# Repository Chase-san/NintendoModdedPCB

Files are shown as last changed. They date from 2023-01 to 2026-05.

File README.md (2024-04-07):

# NintendoModdedPCB

Modifications of my remakes various Nintendo PCB with KiCAD. Usually for F-RAM and battery.

These were designed with the help of Mhouranix1125, which created the excellent [DMG-KGDU-10+](https://github.com/Mhouranix1125/DMG-KGDU-10-Plus-FRAM-Upgraded-PCB)

# License

These boards are released under the Creative Commons Attribution 4.0 International License. See the LICENSE for more details. These boards are intended specifically for the modification of official games. There are better boards for creating flash carts.

# Boards

Click the revision to go to that release of the board (gerber files).

| ID | MOD | Revision |
| :--- | :--- | :---: |
| DMG-A02-MOD | F-RAM | [REV2](https://github.com/Chase-san/NintendoModdedPCB/releases/tag/dmg-a02-mod-rev2) |
| DMG-KGDU-MOD2 | F-RAM, BATTERY | [REV2](https://github.com/Chase-san/NintendoModdedPCB/releases/tag/dmg-kgdu-mod2-rev2) |

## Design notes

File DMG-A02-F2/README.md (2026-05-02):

# DMG-A02-MOD

This is an F-RAM and battery holder upgrade to the DMG-A02-10. This board is good for Pokemon Red, Blue, and Yellow as well many other games.

## Components

This board features a 32-pin ROM and a 28-pin RAM module.

| Ref | Package | Description  | Notes | Part |
| :---: | :---: | :--- | :---- | :--- |
| U1 | SSOP-32W | Program ROM  | | |
| U2 | LQFP-32 | MBC-5 | | |
| U3 | SOIC-28W | F-RAM | | |
| U4 | TSOP-6 | Clock Sync | OR Gate | 74LVC1G332GV,125 |
| C1, C2, C3, C4, C5 | 0603 (in) |  0.015uF - 0.1uF Capacitor | |
| C6 | 0603 (in) | 33pF Capacitor | May be left empty | |
| R1 | 0603 (in) | 10k Ohm Resistor | | |

## Change Log

### REV2 (2023-01-29)
- Added teardrops.

### REV1 (2023-01-21)
- Initial creation.

## Images
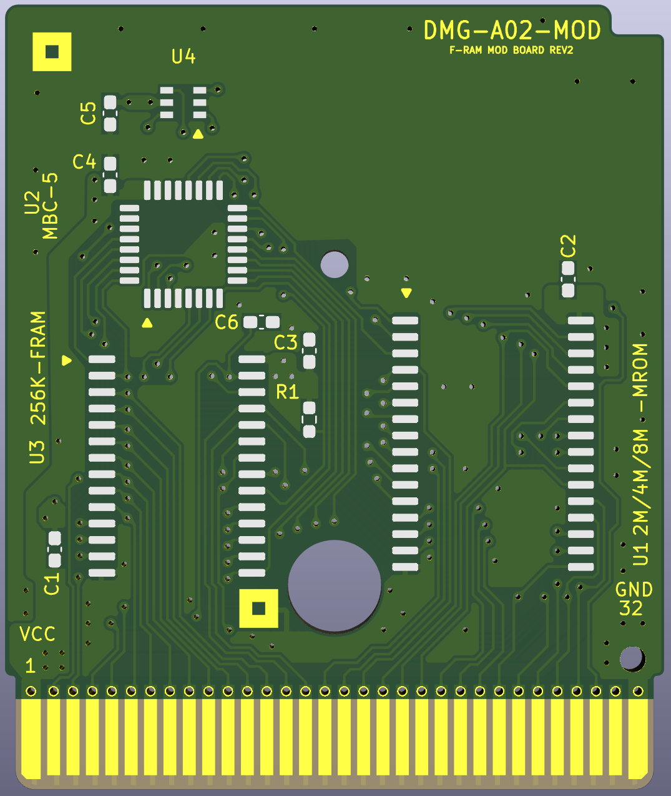
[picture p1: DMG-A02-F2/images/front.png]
Front

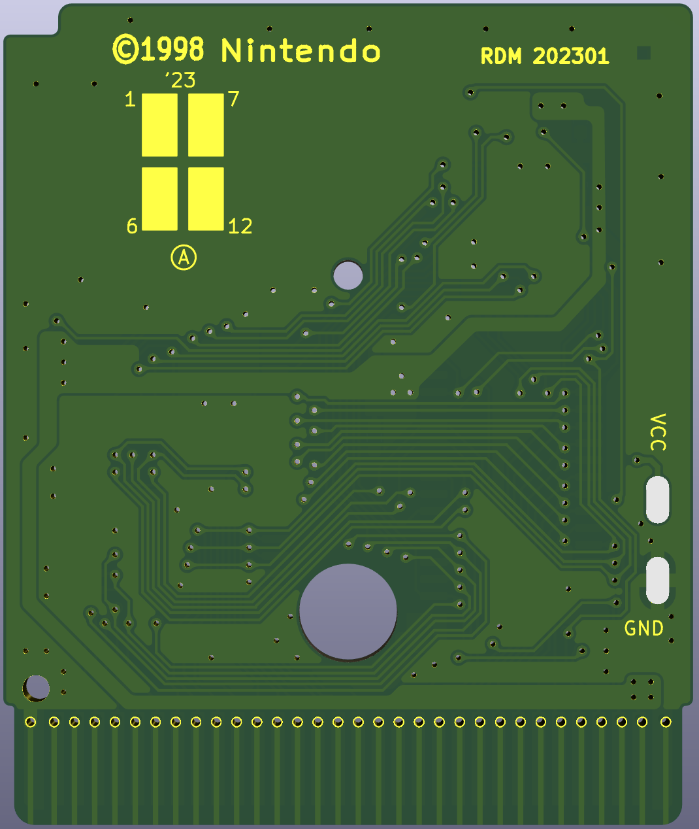
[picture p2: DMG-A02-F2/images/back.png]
Rear


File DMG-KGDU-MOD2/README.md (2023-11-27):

# DMG-KGDU-MOD2

This is an F-RAM and battery holder upgrade to the DMG-KGDU-10.

## Components

This board features a 32-pin ROM and a 28-pin RAM module.

| Ref | Package | Description  | Notes | 
| :---: | :---: | :--- | :---- |
| U1 | TSOP-II-44W | Program ROM  | ~10.1mm wide |
| U2 | LQFP-32 | MBC-3 | |
| U3 | SOIC-28W | F-RAM | ~8.3mm wide |
| U4 | SOIC-8 | System Reset | ~4.3mm wide |
| U5 | SOT-23-5 | Clock Sync | OR Gate |
| C1,C2 | 0603 (in) | 15pF Capacitor | |
| C3,C4,C6 | 0603 (in) | 15nF-0.1uF Capacitor | |
| C5 | 0603 (in) | 33pF Capacitor | May be left empty. |
| R1 | 0603 (in) | 1kOhm Resistor | |
| R2 | 0603 (in) | 330kOhm Resistor | |
| X1 | 6mm x 2mm | 32.768 kHZ Cystal | 12.5 pF Load and 35 kOhm ESR |
| Batt  | CR2025 | Battery Holder | |

It is highly recommended to use the following parts.

| Ref  | Manufacturer | Component |
| :--: | :---: | :---: |
| U3 | Infineon | FM18W08 |
| U5 | Texas Instruments | SN74LVC1G32DBVR |
| Batt | MPD | BK-6219 |

## Images
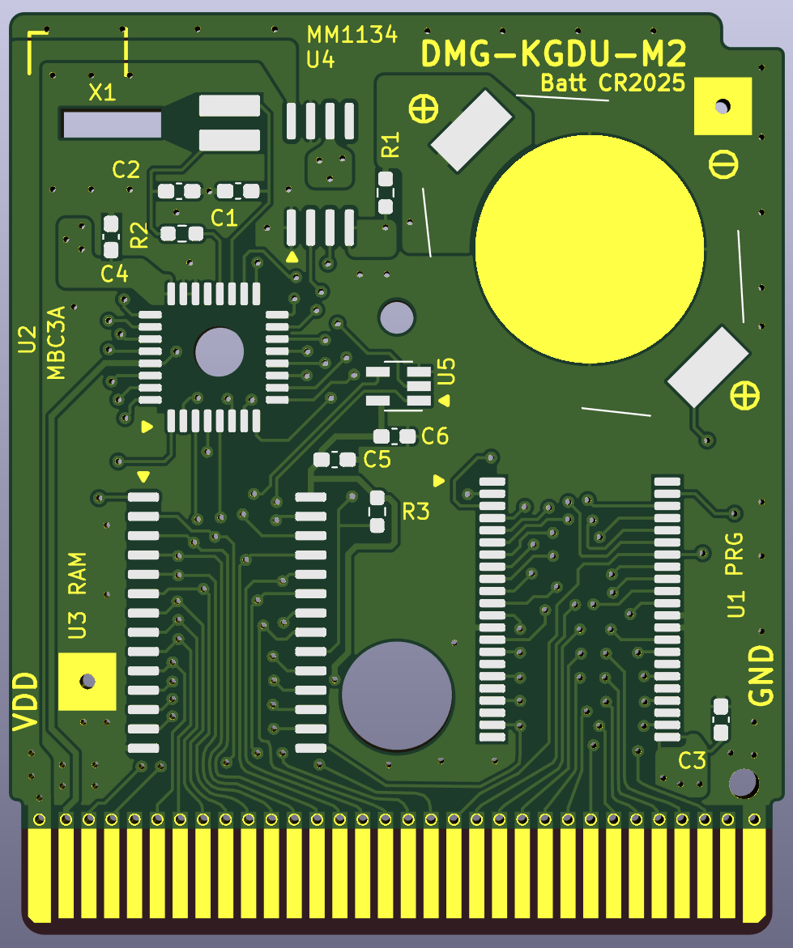
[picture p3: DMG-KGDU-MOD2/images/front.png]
Front

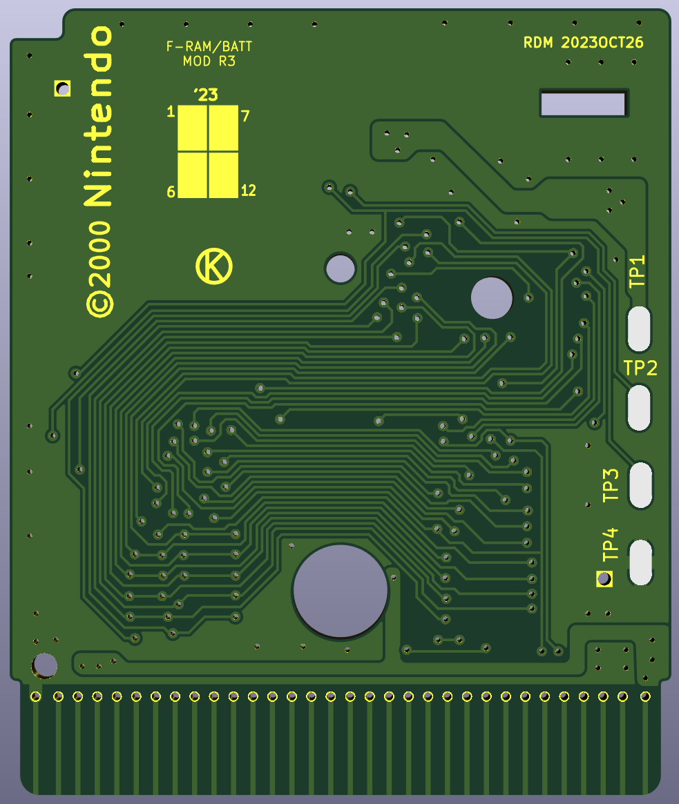
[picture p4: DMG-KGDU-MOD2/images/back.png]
Rear


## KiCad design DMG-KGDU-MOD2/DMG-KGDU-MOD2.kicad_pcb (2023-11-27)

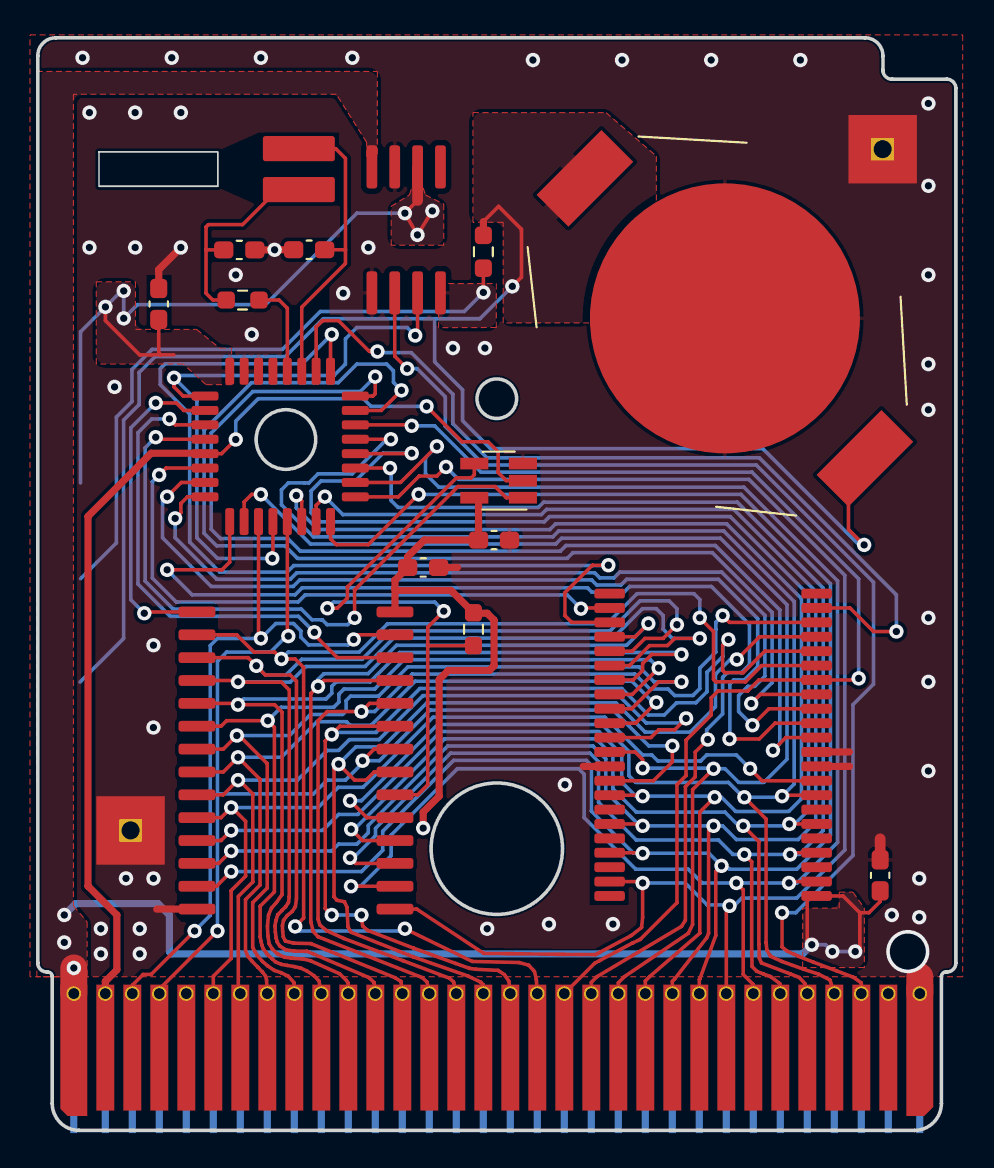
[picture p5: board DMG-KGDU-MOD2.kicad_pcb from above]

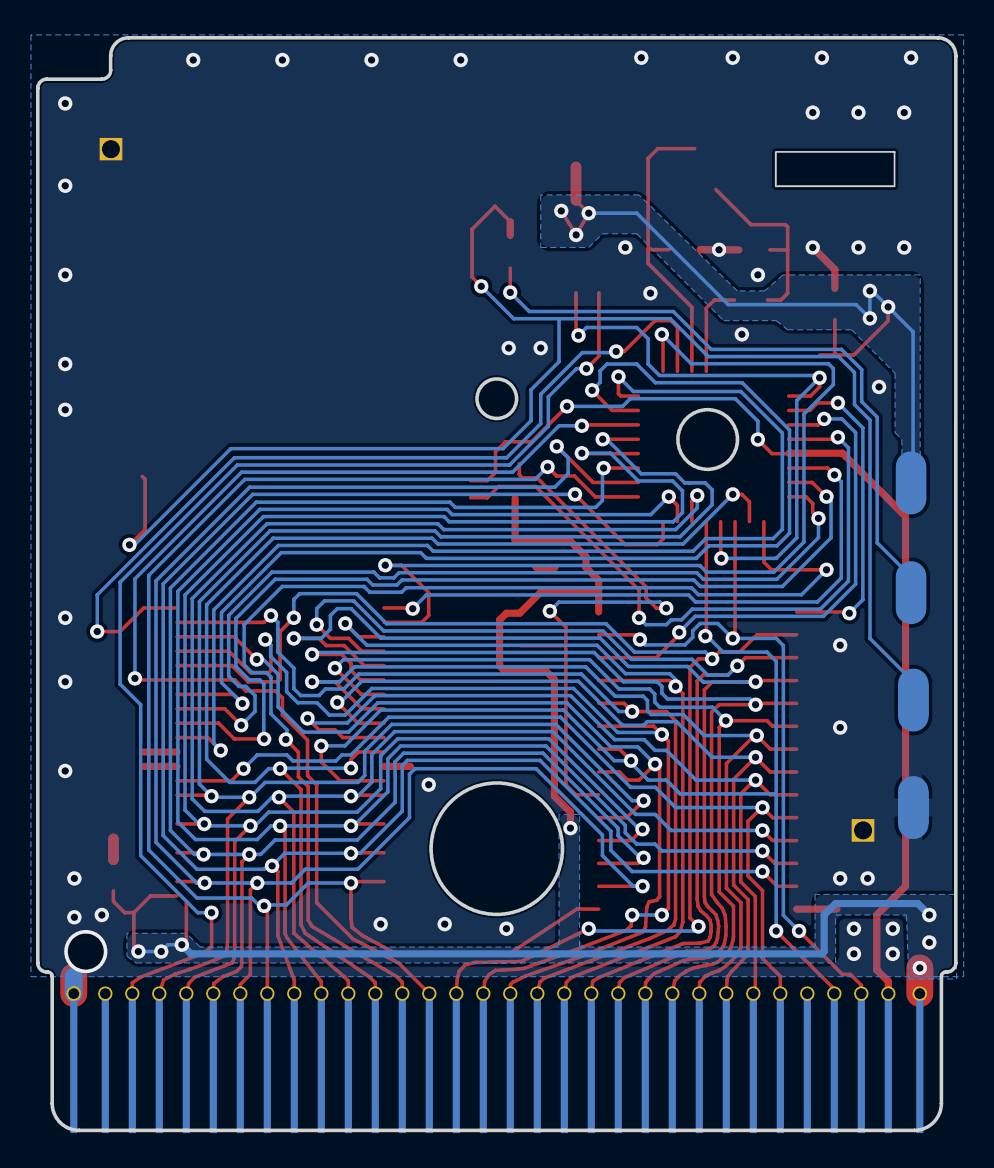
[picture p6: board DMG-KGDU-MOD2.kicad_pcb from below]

Board: 2 copper layers, 51.0 x 60.7 mm, 23 parts (4 on the bottom side), 48 nets.

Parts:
BT1: Batt CR2025; BAT-HLD-002
C1, C2: 15pF; C_0603_1608Metric_Pad1.08x0.95mm_HandSolder
C3, C4, C5, C6: 0.1pF; C_0603_1608Metric_Pad1.08x0.95mm_HandSolder
GND1: GroundPad_Square_TH_3.8mm
GND**: GroundPad_Square_TH_3.8mm
R1: 1kΩ; R_0603_1608Metric_Pad0.98x0.95mm_HandSolder
R2: 330kΩ; R_0603_1608Metric_Pad0.98x0.95mm_HandSolder
R3: 10kΩ; R_0603_1608Metric_Pad0.98x0.95mm_HandSolder
TP1, TP2, TP3, TP4: TestPoint_3.5x1.7mm
U0: CartBus; GameBoy_GamePak_CGB-002_P1.50mm_Edge
U1: PRG; TSOP-II-44_MROM
U2: MBC3A; LQFP-32_MBC
U3: RAM; SOIC-28_SRAM
U4: MM1134; SO-8_SYSRST
U5: 74LVC1G32; SOT-23-5_HandSoldering
X1: Crystal_D2mm_L6mm_Horizontal

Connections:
A00: U0.6, U1.31, U3.10
A01: U0.7, U1.11, U3.9
A02: U0.8, U1.10, U3.8
A03: U0.9, U1.9, U3.7
A04: U0.10, U1.8, U3.6
A05: U0.11, U1.7, U3.5
A06: U0.12, U1.6, U3.4
A07: U0.13, U1.5, U3.3
A08: U0.14, U1.4, U3.25
A09: U0.15, U1.42, U3.24
A10: U0.16, U1.41, U3.21
A11: U0.17, U1.40, U3.23
A12: U0.18, U1.39, U3.2
A13: U0.19, U1.38, U2.14
A14: U0.20, U2.1
A15: U0.21, U1.12, U2.2
AA13: U2.27, U3.26
AA14: U2.26, U3.1
BT+: BT1.1, BT1.2, R1.2, TP3.1
CE: R3.1, U3.20, U5.4
Clock: U0.2, U2.29, U5.2
D0: U0.22, U1.15, U2.6, U3.11
D1: U0.23, U1.17, U2.7, U3.12
D2: U0.24, U1.19, U2.8, U3.13
D3: U0.25, U1.21, U2.9, U3.15
D4: U0.26, U1.24, U2.10, U3.16
D5: U0.27, U1.26, U2.11, U3.17
D6: U0.28, U1.28, U2.12, U3.18
D7: U0.29, U1.30, U2.13, U3.19
GND: BT1.3, C1.1, C2.2, C3.2, C4.2, C5.2, C6.2, GND1.1, GND**.1, TP4.1, U0.32, U1.13, U1.32, U1.33, U2.22, U2.23, U3.14, U4.1, U4.7, U5.3
RA14: U1.37, U2.15
RA15: U1.36, U2.32
RA16: U1.35, U2.31
RA17: U1.34, U2.16
RA18: U1.3, U2.17
RA19: U1.2, U2.30
RA20: U1.43, U2.18
RAMCS: U2.28, U5.1
Read: U0.4, U1.14, U2.5, U3.22
Reset: U0.30, U4.2
SYS_RST: U2.4, U2.25, U4.3
VBATT: R1.1, TP2.1, U4.4
VCC: C3.1, C5.1, C6.1, R3.2, U0.1, U1.23, U3.28, U4.8, U5.5
VOUT: C4.1, TP1.1, U2.24, U4.6
Write: U0.3, U2.3, U3.27
XIN: C1.2, U2.19, X1.1
XOUT: R2.2, U2.20
X_: C2.1, R2.1, X1.2

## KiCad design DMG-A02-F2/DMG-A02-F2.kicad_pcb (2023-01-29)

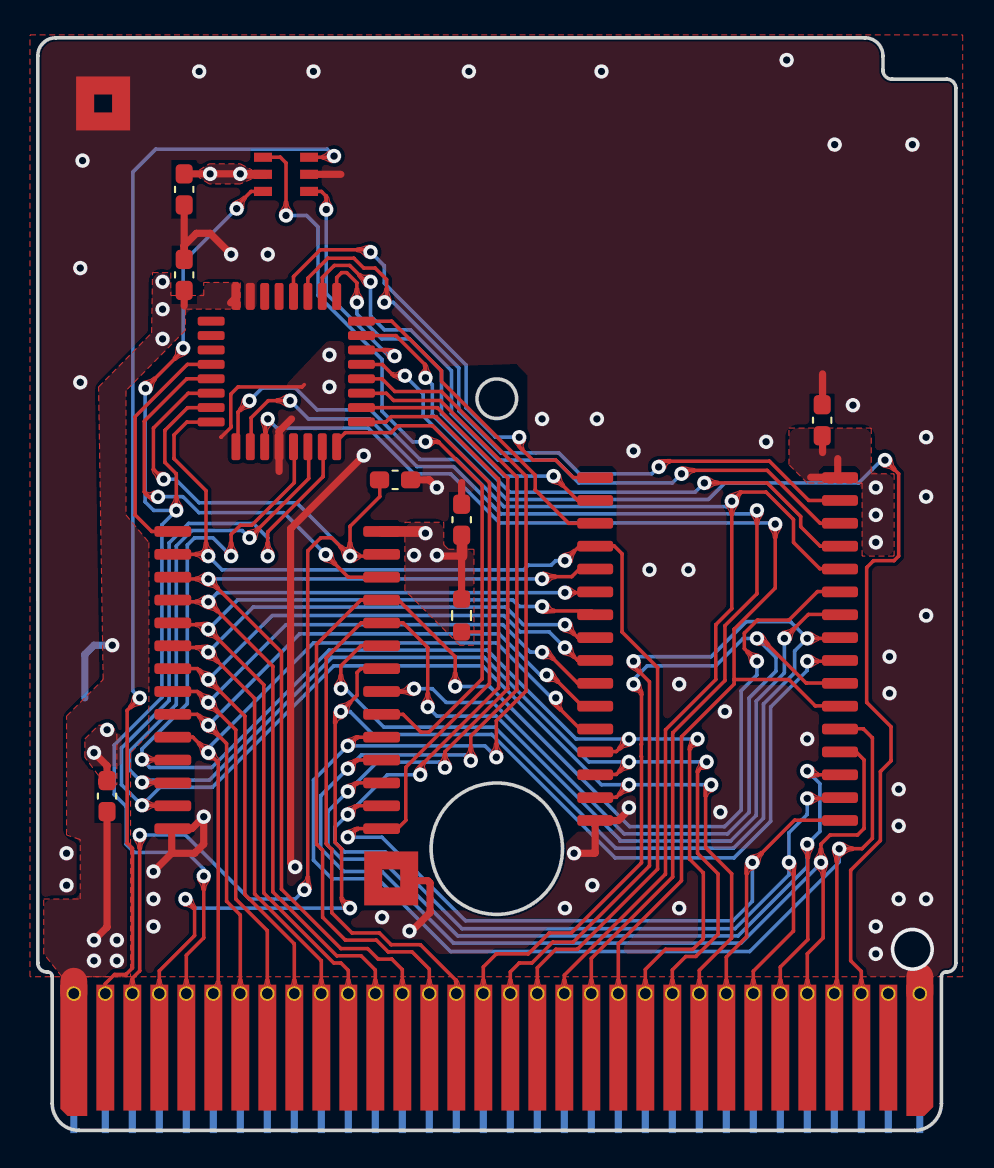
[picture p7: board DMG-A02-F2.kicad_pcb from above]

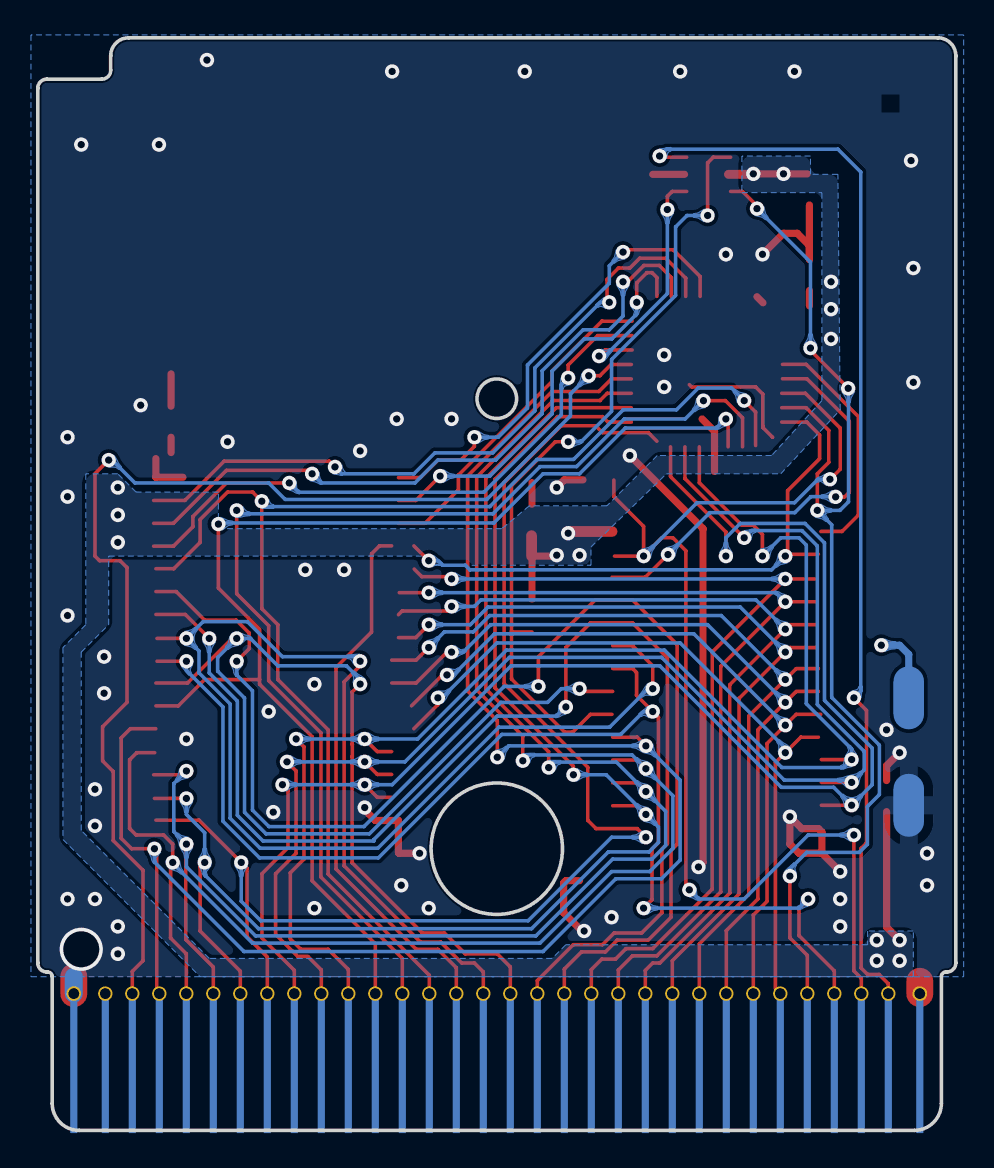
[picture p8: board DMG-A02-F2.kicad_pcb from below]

Board: 2 copper layers, 51.0 x 60.7 mm, 16 parts (2 on the bottom side), 41 nets.

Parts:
C1, C2, C3, C4, C5, C6: ?? F; C_0603_1608Metric_Pad1.08x0.95mm_HandSolder
G1, G2: GroundPad_Square_SMD_3mm
GND: TestPoint_3.5x1.7mm
R1: R_0603_1608Metric_Pad0.98x0.95mm_HandSolder
U0: CartBus; GameBoy_GamePak_CGB-002_P1.50mm_Edge
U1: SSOP-32_MROM
U2: LQFP-32_MBC
U3: SOIC-28_SRAM
U4: TSOP-6_1.65x3.05mm_P0.95mm
VCC: TestPoint_3.5x1.7mm

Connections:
A00: U0.6, U1.12, U3.10
A01: U0.7, U1.11, U3.9
A02: U0.8, U1.10, U3.8
A03: U0.9, U1.9, U3.7
A04: U0.10, U1.8, U3.6
A05: U0.11, U1.7, U3.5
A06: U0.12, U1.6, U3.4
A07: U0.13, U1.5, U3.3
A08: U0.14, U1.27, U3.25
A09: U0.15, U1.26, U3.24
A10: U0.16, U1.23, U3.21
A11: U0.17, U1.25, U3.23
A12: U0.18, U1.4, U2.32, U3.2
A13: U0.19, U1.28, U2.1
A14: U0.20, U2.2
A15: U0.21, U1.22, U2.3
CS: U0.5, U2.31, U4.6
Clock: U0.2, U4.3
D0: U0.22, U1.13, U2.5, U3.11
D1: U0.23, U1.14, U2.6, U3.12
D2: U0.24, U1.15, U2.7, U3.13
D3: U0.25, U1.17, U2.8, U3.15
D4: U0.26, U1.18, U2.9, U3.16
D5: U0.27, U1.19, U2.10, U3.17
D6: U0.28, U1.20, U2.11, U3.18
D7: U0.29, U1.21, U2.12, U3.19
GND: C1.2, C2.2, C3.2, C4.2, C5.2, C6.2, G1.1, G2.1, GND.1, U0.32, U1.16, U2.4, U2.23, U3.14, U4.2
OR_A: U2.14, U4.1
OR_Y: R1.1, U3.20, U4.4
RA14: U1.29, U2.15
RA15: U1.3, U2.16
RA16: U1.2, U2.17
RA17: U1.30, U2.18
RA18: U1.31, U2.19
RA19: U1.1, U2.20
Read: U0.4, U1.24, U3.22
Reset: U0.30, U2.13
SA13: U2.29, U3.26
SA14: U2.28, U3.1
VCC: C1.1, C2.1, C3.1, C4.1, C5.1, R1.2, U0.1, U1.32, U2.24, U3.28, U4.5, VCC.1
Write: C6.1, U0.3, U2.30, U3.27

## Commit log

2023-01-21 Modded Boards
    [DMG-KGDU-MOD.kicad_pcb, DMG-KGDU-MOD2.kicad_pcb]
2023-01-21 Generate Gerber
    [DMG-KGDU-MOD.kicad_pcb, DMG-KGDU-MOD2.kicad_pcb]
2023-01-21 A02-MOD and REV2 KGDU
    [DMG-A02-MOD.kicad_pcb, DMG-KGDU-MOD.kicad_pcb, DMG-KGDU-MOD2.kicad_pcb]
2023-01-22 Fix text placement.
    [DMG-A02-MOD.kicad_pcb]
2023-01-29 Update A02 to REV2
    [DMG-A02-MOD.kicad_pcb]
2023-01-29 Fixing irrelevant DRC warning.
    [DMG-A02-MOD.kicad_pcb]
2023-02-03 Update footprints
2023-06-19 Update KGDU BOM.
2023-11-27 Update for new stuff.
    [DMG-KGDU-MOD.kicad_pcb, DMG-KGDU-MOD2.kicad_pcb]

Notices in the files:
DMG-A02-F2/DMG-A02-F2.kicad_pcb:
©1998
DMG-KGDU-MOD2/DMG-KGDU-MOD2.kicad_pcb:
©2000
